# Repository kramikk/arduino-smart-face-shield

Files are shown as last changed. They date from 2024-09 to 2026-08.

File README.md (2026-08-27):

# Arduino Smart Face Shield (2022)

<p align="center">
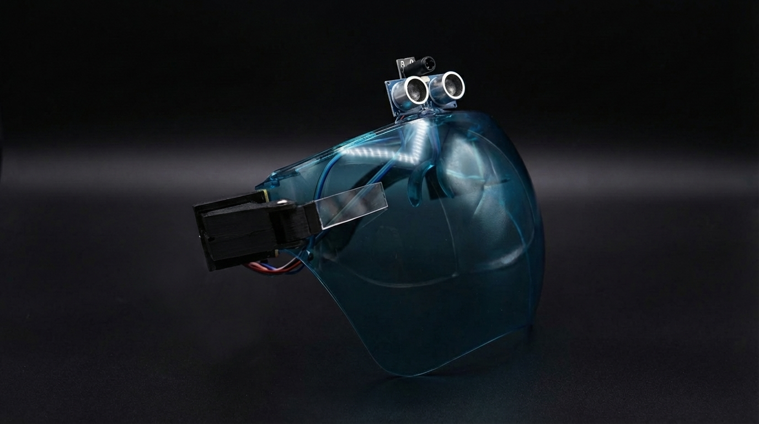
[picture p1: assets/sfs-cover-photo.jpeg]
  
</p>

## Introduction

This project is my Senior High Practical Research 2 Scientific Investigatory Project (SIP), in which it was completed on January 2022. It was developed as a response to the COVID-19 pandemic, aimed at improving public health safety. Our Arduino-based smart face shield was designed to provide a hands-free solution for temperature scanning and monitoring.

The smart face shield detects the temperature of surrounding individuals without any physical contact, offering a fast and effective way to monitor for potential fever—a common symptom of COVID-19. This device not only helps in minimizing close contact but also ensures a quick and efficient method to assess temperatures in public spaces.

This project utilizes an Arduino with an ultrasonic sensor and an infrared temperature sensor to measure both the distance and the temperature of a person. The values are displayed on an OLED screen which the user can view through a reflection, and a vibration motor is triggered if the temperature exceeds a certain threshold (37.5°C). The project also includes a real-time clock (RTC) module to display the current date and time on the OLED display.

## Components

<p align="center">
  Smart Face Shield in action
</p>

- **Arduino Nano** (for portability)
- **Ultrasonic Sensor (HC-SR04)**: Measures distance in centimeters.
- **Infrared Temperature Sensor (MLX90614)**: Measures object and ambient temperature.
- **OLED Display (128x64)**: Displays date, time, temperature, and distance.
- **Vibration Motor**: Activated when the object's temperature exceeds 37.5°C.
- **RTC Module (DS3231)**: Displays the current date and time.
- **Additional Power Supply Pin (VCC2)**: Supplies power to the ultrasonic sensor.

## Libraries Used
You need to install the following libraries in your Arduino IDE:
- [NewPing](https://bitbucket.org/teckel12/arduino-new-ping/wiki/Home): For the ultrasonic sensor.
- [Adafruit MLX90614](https://github.com/adafruit/Adafruit-MLX90614-Library): For the infrared temperature sensor.
- [Adafruit GFX](https://github.com/adafruit/Adafruit-GFX-Library): For controlling the OLED display.
- [Adafruit SSD1306](https://github.com/adafruit/Adafruit_SSD1306): For the OLED screen communication.
- [RTClib](https://github.com/adafruit/RTClib): For the real-time clock module.

## Features
<p align="center">
  Smart Face Shield
</p>

- **Distance Measurement**: Measures the distance using the ultrasonic sensor.
- **Temperature Measurement**: Measures the object's temperature using the MLX90614 sensor.
- **OLED Display**: Displays the current date, time, temperature, and distance.
- **Vibration Alert**: The vibration motor is activated if the object's temperature is equal to or above 37.5°C.
- **Real-Time Clock (RTC)**: Shows the current date and time using the DS3231 module.

## How It Works
<p align="center">
  Smart Face Shield
</p>

1. The ultrasonic sensor detects the distance to an object in centimeters.
2. The infrared temperature sensor measures an object temperature.
3. The current date and time are fetched from the RTC module.
4. If the measured object temperature is greater than or equal to 37.5°C, the vibration motor is triggered.
5. All the data (date, time, distance, temperature) is displayed on the OLED screen which is reflected through a mirror into a transparent surface.
6. The data is also printed to the Serial Monitor for debugging purposes.

## Circuit Diagram
Make sure to connect the following components correctly:

- **Ultrasonic Sensor (HC-SR04)**:
  - Trigger pin to Arduino pin 11
  - Echo pin to Arduino pin 12
  - VCC to Arduino 5V (or additional 5V pin)
  - GND to Arduino GND
- **Infrared Temperature Sensor (MLX90614)**:
  - SDA to Arduino A4
  - SCL to Arduino A5
  - VCC to Arduino 3.3V
  - GND to Arduino GND
- **OLED Display (SSD1306 128x64)**:
  - SDA to Arduino A4
  - SCL to Arduino A5
  - VCC to Arduino 5V
  - GND to Arduino GND
- **RTC (DS3231)**:
  - SDA to Arduino A4
  - SCL to Arduino A5
  - VCC to Arduino 5V
  - GND to Arduino GND
- **Vibration Motor**:
  - Vibration motor pin to Arduino pin 10
  - Ground pin to GND

## Code
You can find the source code in the `asf.ino` file. The main logic involves the following:
- Initialization of all sensors and the OLED screen.
- Continuously fetch and display the date, time, temperature, and distance.
- Activate the vibration motor based on the temperature threshold.

## How to Use
1. **Upload the code** to your Arduino board using the Arduino IDE.
2. **Install the required libraries** in your Arduino IDE if you haven't already.
3. **Connect the components** according to the circuit diagram.
4. Open the **Serial Monitor** to view the real-time data output.
5. Observe the **OLED display** for real-time distance, temperature, date, and time.
6. If the temperature exceeds 37.5°C, the vibration motor will be activated.
7. Once working, print all the parts from [assets folder](https://github.com/kramikkk/arduino-smart-face-shield/tree/main/case-3d-model) and place the components inside it.

## Poster
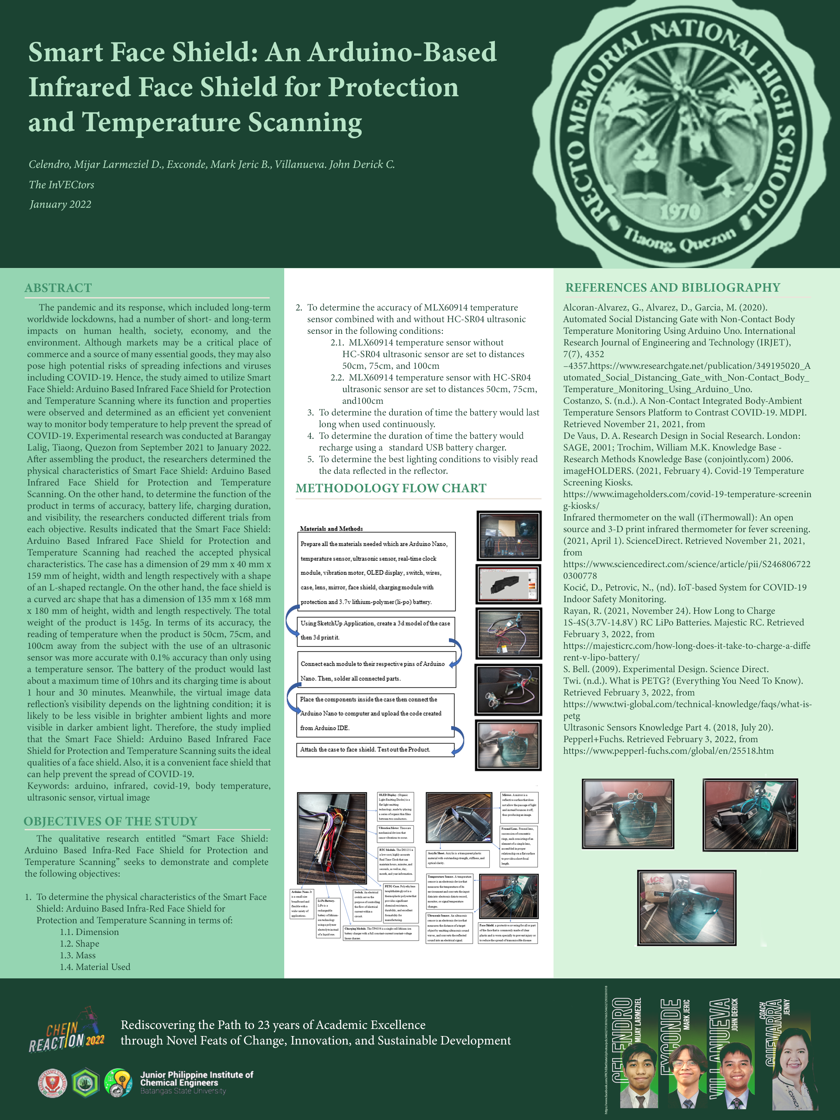
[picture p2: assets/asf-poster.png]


## Extra
[Smart-Face-Shield-Research-Paper.pdf](https://github.com/kramikkk/arduino-smart-face-shield/tree/main/assets/Smart-Face-Shield-Research-Paper.pdf) 
## License
This project is licensed under the MIT License. You are free to use, modify, and distribute this project as long as proper credit is given to the author.

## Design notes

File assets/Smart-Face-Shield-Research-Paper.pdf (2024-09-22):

Smart Face Shield: Arduino Based Infra-Red Face Shield for Protection and Temperature

Scanning

A Research Paper

Presented to the Senior High School Department

Of Recto Memorial National High School

In Partial Fulfilment

Of the Requirements for the Subject

Practical Research

By:

Celendro, Mijay Larmeziel D.

Exconde, Mark Jeric B.

Villanueva, John Derick D.

January 2022

ii

TABLE OF CONTENTS

PRELIMINARIES | PAGES

CHAPTER 1- THE PROBLEM AND ITS BACKGROUND

CHAPTER II- REVIEW OF RELATED LITERATURE

CHAPTER III- RESEARCH METHODOLOGY

iii

CHAPTER IV- PRESENTATION, ANALYSIS, AND INTERPRETATION OF DATA

I. The Physical Characteristics of the Smart Face Shield: Arduino Based Infra-red

Face shield for Protection and Temperature

II. | The accuracy of MLX60914 temperature sensor combined with and without HC-
III. | The duration of time the battery of Smart Face Shield: Arduino Based Infra-red
| Face shield for Protection and Temperature
IV. | The duration of time the battery of Smart Face Shield: Arduino Based Infra-red
| Face shield for Protection and Temperature Scanning would
V. The best lighting conditions to visibly read the data reflected the reflector of the

Smart Face Shield: Arduino Based Infra-red Face shield for Protection and

CHAPTER V- SUMMARY, CONCLUSIONS, AND RECOMMENDATIONS

iv

APPENDICES

v

ABSTRACT

The pandemic and its response, which included long-term worldwide lockdowns, had a

number of short- and long-term impacts on human health, society, economy, and the environment.

Although markets may be a critical place of commerce and a source of many essential goods, they

may also pose high potential risks of spreading infections and viruses including COVID-19.

Hence, the study aimed to utilize Smart Face Shield: Arduino Based Infrared Face Shield for

Protection and Temperature Scanning where its function and properties were observed and

determined as an efficient yet convenient way to monitor body temperature to help prevent the

spread of COVID-19. Experimental research was conducted at Barangay Lalig, Tiaong, Quezon

from September 2021 to January 2022. After assembling the product, the researchers determined

the physical characteristics of Smart Face Shield: Arduino Based Infrared Face Shield for

Protection and Temperature Scanning. On the other hand, to determine the function of the product

in terms of accuracy, battery life, charging duration, and visibility, the researchers conducted

different trials from each objective. Results indicated that | the | Smart Face Shield: Arduino Based
Infrared Face Shield for Protection and Temperature Scanning | had reached the accepted physical

characteristics. The case has a dimension of 29 mm x 40 mm x 159 mm of height, width and length

respectively with a shape of an L-shaped rectangle. On the other hand, the face shield is a curved

arc shape that has a dimension of 135 mm x 168 mm x 180 mm of height, width and length

respectively. The total weight of the product is 145g. In terms of its accuracy, the reading of

temperature when the product is 50cm, 75cm, and 100cm away from the subject with the use of

an ultrasonic sensor was more accurate with 0.1% accuracy than only using a temperature sensor.

The battery of the product would last about a maximum time of 10hrs and its charging time is

about 1 hour and 30 minutes. Meanwhile, the virtual image data reflection’s visibility depends on

the lighting condition; it is likely to be less visible in brighter ambient lights and more visible in

darker ambient light. | Therefore, the study implied that the | Smart Face Shield: Arduino Based

Infrared Face Shield for Protection and Temperature Scanning suits the ideal qualities of a face

shield. Also, it is a convenient face shield that can help prevent the spread of COVID-19.

Keywords: arduino, infrared, covid-19, body temperature, ultrasonic sensor, virtual image

Chapter I

THE PROBLEM AND ITS BACKGROUND

Technology has still risen up for the past years despite the pandemic. In the malls and

airports, they use a device called ‘Kiosks’ to thermal scan the body temperatures of who passes

by. As stated by imageHOLDERS (2021), fever detection is one of the methods in identifying

COVID-19 and other infectious illnesses which may help to reduce the spread. Inspired by the

concept of modern Smart Glasses, Mauer (2016) created an Arduino Glasses: a head-mounted

display (HMD) for Multimeter. This device displays data of a multimeter in form of the virtual

image reflected into the eye. The researchers then used the ideology and design of Mauer’s project

to create Smart Face Shield: Arduino Based Infra-red Face shield for Protection and Temperature

Scanning. Also, the researchers, therefore, conclude that the use of Arduino and Infrared

technology inspired by the concept of thermal and virtual imaging, are the necessary means to

achieve the goals of the research.

Statement of the problem

The qualitative research entitled “Smart Face Shield: Arduino Based Infra-Red Face

Shield for Protection and Temperature Scanning” seeks to demonstrate and complete the

following objectives:

1. To determine the physical characteristics of the Smart Face Shield: Arduino Based Infra-

Red Face Shield for Protection and Temperature Scanning in terms of:

1.1. Dimension

1.2. Shape
1.3. Mass
1.4. Material Used
2. To determine the accuracy of MLX60914 temperature sensor combined with and without

HC-SR04 ultrasonic sensor in the following conditions:

2.1. MLX60914 temperature sensor without HC-SR04 ultrasonic sensor are set to distances

50cm, 75cm, and 100cm

2.2. MLX60914 temperature sensor with HC-SR04 ultrasonic sensor are set to distances

50cm, 75cm, and 100cm

3. To determine the duration of time the battery would last long when used continuously.
4. To determine the duration of time the battery would recharge using a standard USB battery

charger.

5. To determine the best lighting conditions to visibly read the data reflected in the reflector.

Significance of the Study

This study entitled | “Smart Face Shield: Arduino Based Infra-Red Face Shield for
Protection and Temperature Scanning” | aimed to come up with a new way to help prevent the

spread of COVID-19. This will be convenient and useful for awareness and protection.

Moreover, this will ensure people’s health safety against COVID-19. The use of Arduino

and infra-red temperature sensor can greatly help in the pandemic since knowing the body temperature of a person would give great advantages while also using the face shield in protection

for droplets size viruses from people nearby.

This study will be beneficial for people, especially the consumers, workers, and vendors,

as well as producers to be able to reduce the potential further exposure of their health risks while

browsing or selling products at public markets.

This study also benefits future researchers, in adding to the much-needed related literature

review, strengthening conceptual and theoretical framework as well as pursuing this field of the

proposed study and may come up with future innovations using the same materials to contribute

to the development of technology.

In addition, this research can be a good starting point for another or other developmental

researchers to invent a similar product that can be used to help prevent the further spread of the

virus.

The study wanted to prove that with the use of the said product, people can maximize their

protection, especially from the data accuracy of temperature sensors. It can be recharged up fast

and last long for daily convenient and efficient use.

The findings of this study will rebound to the benefit of society considering that thermal

scanning will be a great help on our daily shopping.

The Smart Face Shield: Arduino Based Infra-Red Face Shield for Protection and

Temperature Scanning can be practically useful enough since the need for protection is

increasingly becoming important.

Scope and Delimitation of the Study

The focus of this research paper entitled “Smart Face Shield: Arduino Based Infra-Red

Face Shield for Protection and Temperature Scanning” is to determine the effectiveness and

functionality of using Arduino and infrared technology to read nearby bodies temperature.

The findings of the study were based on the observations that were answered by the five

objectives of the study: (1) physical characteristics of the Smart Face Shield Arduino Based Infra-

Red Face Shield for Protection and Temperature Scanning, (2) accuracy of MLX60914

temperature sensor combined with and without HC-SR04 ultrasonic sensor, (3) duration of time

the battery would last long when used continuously, (4) the duration of time the battery would

recharge using a standard USB battery charger, (5) best lighting conditions to visibly read the data

reflected to the reflector.

In addition, because of the COVID-19, the study and testing of the product will be

conducted within the researchers’ house premises only since they are limited to go outside

considering the quarantine protocols implemented in the community. The respondent person for

testing of the product needs parents’ consent to secure the safety of the person/s who test the

product. However, during the process of this paper, communication through the use of digital

devices and the internet will be considered for research purposes.

The study only used the available market modules and sensor since the researchers aren’t

capable of producing self-made sensors or company devices that can make the product better but

more expensive.

This study was conducted from September 2021 to January 2022.

Conceptual Framework

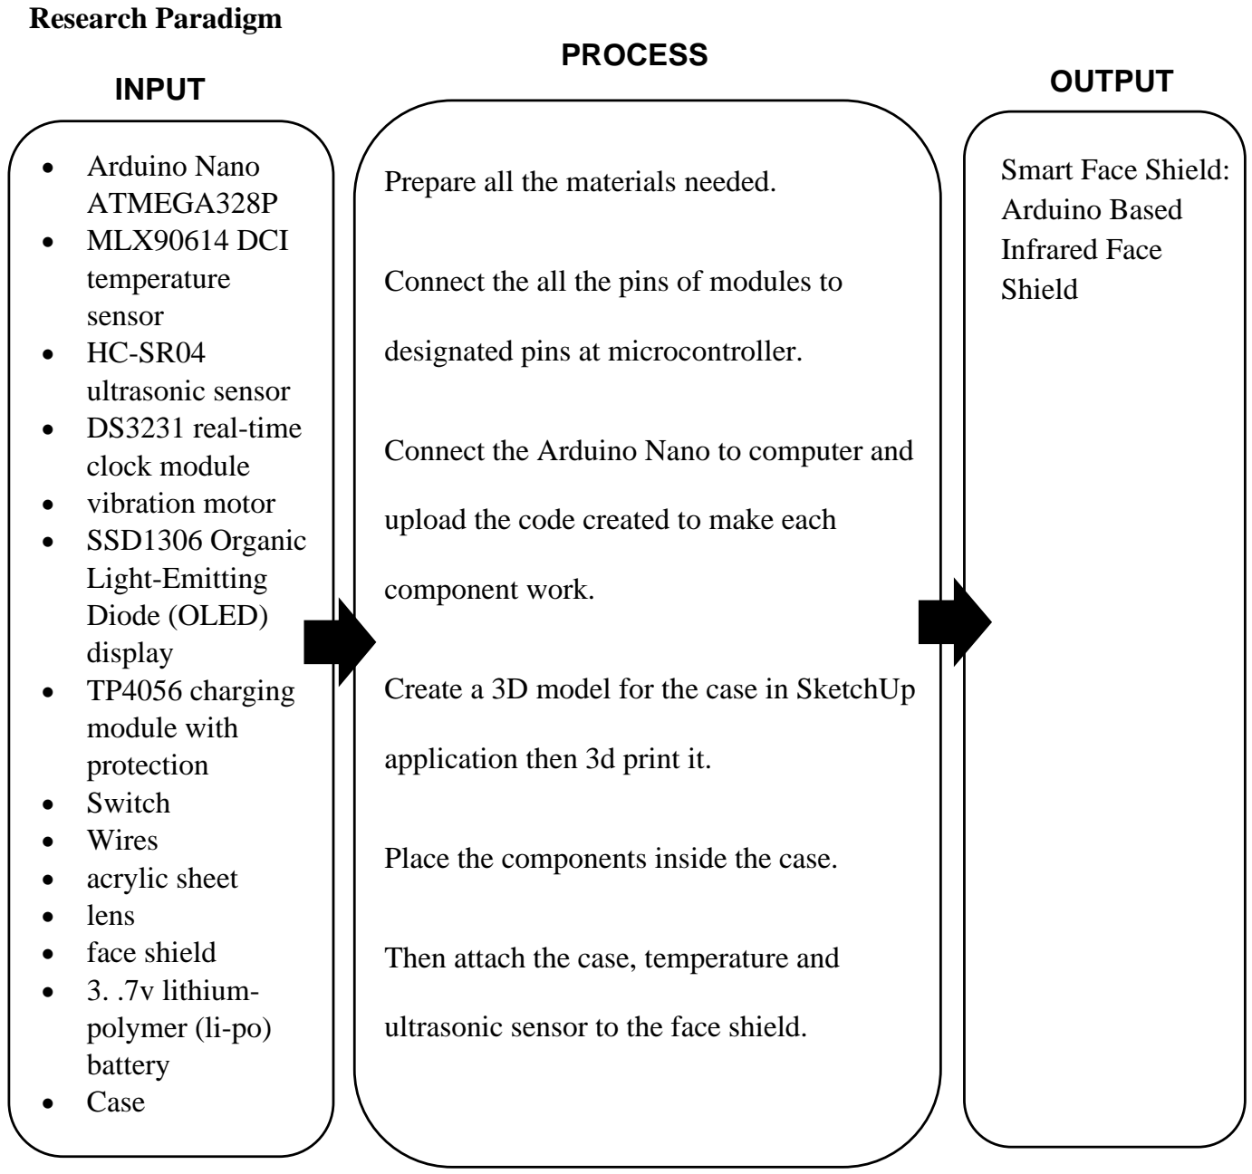
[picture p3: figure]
Research Paradigm; • Arduino Nano ATMEGA328P • MLX90614 DCI temperature sensor • HC-SR04 ultrasonic sensor • DS3231 real-time clock module • vibration motor • SSD1306 Organic Light-Emitting Diode (OLED) display • TP4056 charging module with protection • Switch • Wires • acrylic sheet • lens • face shield • 3. .7v lithium- polymer (li-po) battery • Case; Smart Face Shield: Arduino Based Infrared Face Shield; Prepare all the materials needed.; Connect the all the pins of modules to; designated pins at microcontroller.; upload the code created to make each; component work.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

Figure 1. Input, Process, Output (IPO) of the Smart Face Shield: Arduino Based Infrared Face shield for temperature scanning and protection

Figure 1 shows the Input, Process, and Output wherein the inputs are the Arduino Nano

ATMEGA328P, MLX90614 DCI temperature sensor, HC-SR04 ultrasonic sensor, DS3231 real-

time clock module, vibration motor, SSD1306 Organic Light-Emitting Diode (OLED) display,

Connect the Arduino Nano to computer and

Create a 3D model for the case in SketchUp switch, wires, acrylic sheet, lens, mirror, face shield, TP4056 charging module with protection,

3.7v lithium-polymer (Li-po) battery and case. The process shows that OLED display, RTC

module, temperature sensor, ultrasonic sensor, vibration motor, charging module are to be

connected to the Arduino Nano. The battery would be connected to the charging module. 3d model

of the case should be created and printed. The components would be placed inside the case. Lastly,

Temperature and the ultrasonic sensor would be placed on the forehead level of the face shield

while the case is attached to the right side.

Definition of terms

For clear understanding, the following terms were defined conceptually or operationally:

Arduino - Open-source electronic prototyping platform enabling users to create interactive

electronic objects.

Infra-red - Is electromagnetic radiation (EMR) with wavelengths longer than those of visible

light.

Infra-red sensor - An infrared sensor (IR sensor) is a radiation-sensitive optoelectronic

component with spectral sensitivity in the infrared wavelength range 780 nm … 50 µm.

Covid-19 - stands for Coronavirus Disease 2019 and is a highly contagious disease caused by a

newly discovered coronavirus.

Temperature - is a measure of the average kinetic energy of the atoms or molecules in the system.

Quarantine Protocols - separating and restricting the movement of the people who are exposed

or are potentially exposed to a contagious disease

Pandemic - refers to the proficiency of disease (especially, a virus) to spread or be prevalent to a

country or the whole world, affecting almost the whole population.

Sensor - a device that detects or measures a physical property and records, indicates, or otherwise

responds to it.

Thermal Imaging - Thermal imaging is simply the process of converting infrared (IR) radiation

(heat) into visible images that depict the spatial distribution of temperature differences in a scene

viewed by a thermal camera.

Chapter II

REVIEW OF RELATED LITERATURE AND STUDIES

This chapter presents the different local and foreign literature and studies that are relevant

to the present research.

Related Studies

Local Studies

In a study conducted by Alcoran-Alvarez, et al. (2020) entitled “Automated Social

Distancing Gate with Non-Contact Body Temperature Monitoring using Arduino Uno”, there is a

Thermal gate with the components of Arduino R3, a Long-range Infrared proximity sensor,

Ultrasonic sensor, Speaker, Infrared proximity sensor, Infrared thermometer sensor, LCD module,

Buzzer.

In their research product, there is a long-range sensor (infrared proximity) that points to

the ground to detect the incoming person into the gate, then the speaker sends a signal to the other

person, the person that enters the limit of 1-meter social distancing after the point of entry behind

the first person and within the middle of the gate the body temperature will be scanned and

displayed on the LCD and the buzzer will, alarm if the person enters the gate has a body

temperature greater than 37.5 degrees Celsius to notify the assigned gate personnel.

They have been proven that social distancing can be followed and at the same time/body

temperature scanning of one person can also be done.

Foreign Studies

In the study entitled “Infrared thermometer on the wall (iThermowall): An open-source

and 3-D print infrared thermometer for fever screening” by Abuzairi, Sumantri, et, al. (2020), they

a made low-cost non-contact infrared thermometer in the wall that they called iThermowall. This

device is designed to automatically measure and detect the body’s temperature where there is no

one to operate manual thermometers. The goal of their product is to address the obstacle in using

a non-contact handheld IR thermometer, which is proven to be effective yet still depends on the

operator and the distance between foreheads.

To make the product easily reproducible, the researchers used a readily accessible module

and a 3-D printer. The electronic components consist of a microcontroller unit (MCU), OLED

display, LED, infrared thermometer sensor, infrared proximity sensor, buzzer, charger module,

step-up converter, and battery. The MCU employed open-source Arduino Nano microcontrollers

to read the data from the Infrared Thermometer then write the data into an OLED display.

Moreover, according to Costanzo and Flores (2020) in their study entitled ‘A Non-Contact

Integrated Body-Ambient Temperature Sensors Platform to Contrast COVID-19” the combination

of an infrared thermometer with a capacitive humidity sensor can provide a quick and accurate

tool for remotely monitoring both ambient and body temperature in pandemic circumstances such

as COVID-19. They used an infrared sensor for measuring body temperature and a capacitive

relative humidity (RH) sensor for the ambient temperature, while the Arduino microcontroller

displayed the data collected.

Another research entitled “IoT based System for COVID 19 Indoor Safety Monitoring” by

Petrović and Kocić (2020), made an IoT device intended for contactless temperature sensing, mask detection, and social distancing check. Arduino Uno relies upon as a subsystem for contactless

temperature sensing with the use of infrared sensors or thermal cameras.

On the other hand, leveraging computer vision techniques on camera-equipped Raspberry

Pi is used for mask detection and for checking social distancing.

As stated in the study Nethra, Nagdeepa, et, al. (2021) entitled “Contactless Mobile

Thermometer”, social distancing can’t be ensured by conventional thermometers thus the

researchers decided to produce Bluetooth-primarily based contactless mobile thermometer with

thermal screening functionality delivered to cellular phones. To show the temperature Arduino

Nano is necessary as well as an infrared sensor. The objective of their study is to read temperature

easily and handily that have broad variation for dimension temperature where you can display

accurate temperature scanning in a virtual manner.

CHAPTER III

RESEARCH METHODOLOGY

This chapter presents and discusses the methodology and procedures applied in the

conduct of the study. It contains the materials and methods, research design, research procedures,

and statistical treatment.

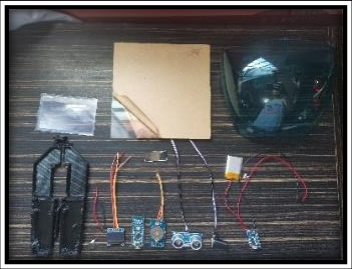
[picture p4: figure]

Materials and Methods

Prepare all the materials needed which are Arduino Nano,

temperature sensor, ultrasonic sensor, real-time clock

module, vibration motor, OLED display, switch, wires,

case, lens, mirror, face shield, charging module with

protection and 3.7v lithium-polymer (li-po) battery.

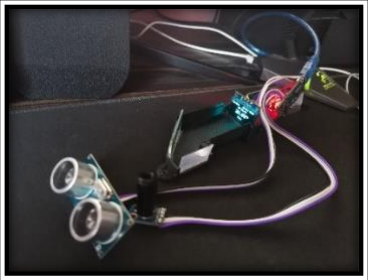
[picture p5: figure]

Connect each module to their respective pins of Arduino

Nano. Then, solder all connected parts.

Place the components inside the case then connect the

Arduino Nano to computer and upload the code created

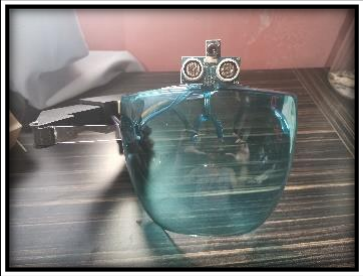
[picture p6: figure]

from Arduino IDE.

Attach the case to face shield. Test out the Product.

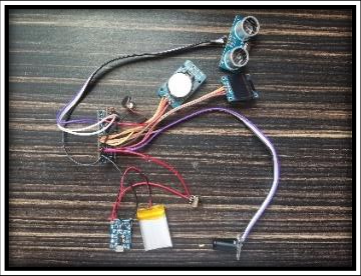
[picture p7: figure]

Using SketchUp Application, create a 3d model of the case

then 3d print it.

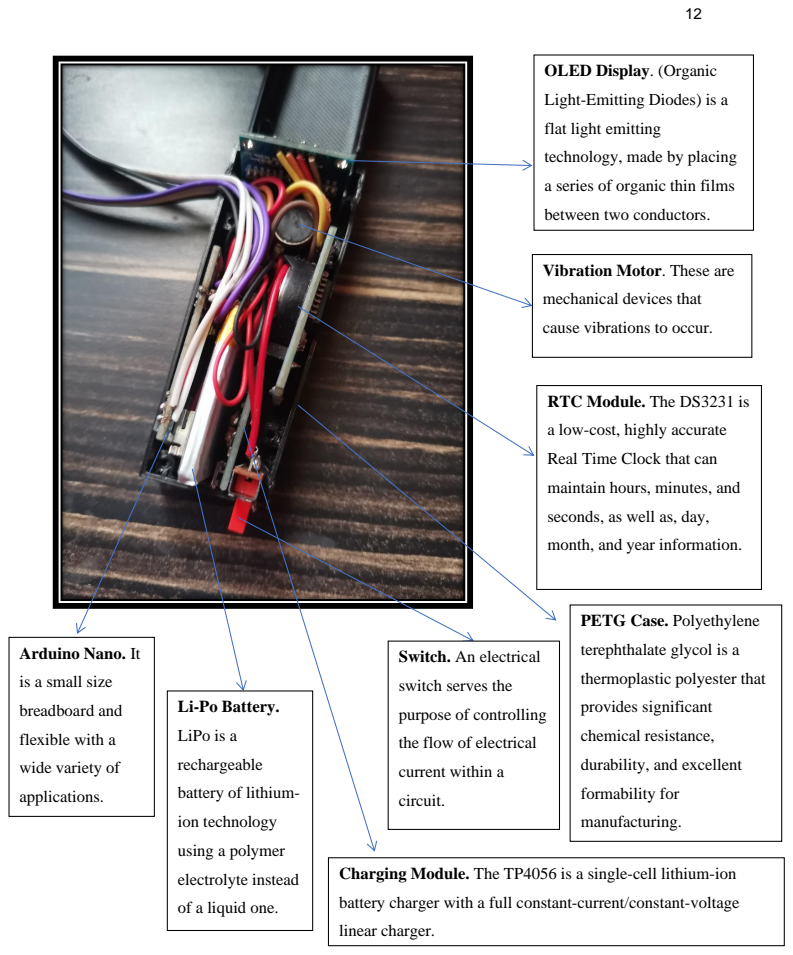
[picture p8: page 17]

OLED Display. (Organic
Light-Emitting Diodes) is a
flat light emitting
technology, made by placing
a series of organic thin films
between two conductors.

Vibration Motor. These are
mechanical devices that
cause vibrations to occur.

RTC Module. The DS3231 is
a low-cost, highly accurate
Real Time Clock that can
maintain hours, minutes, and
seconds, as well as, day,
month, and year information.

PETG Case. Polyethylene
terephthalate glycol is a
thermoplastic polyester that
provides significant
chemical resistance,
durability, and excellent
formability for
manufacturing.

Arduino Nano. It
is a small size
breadboard and
flexible with a
wide variety of
applications.

Switch. An electrical
switch serves the
purpose of controlling
the flow of electrical
current within a
circuit.

Li-Po Battery.
LiPo is a
rechargeable
battery of lithium-
ion technology
using a polymer
electrolyte instead
of a liquid one.

Charging Module. The TP4056 is a single-cell lithium-ion
battery charger with a full constant-current/constant-voltage
linear charger.

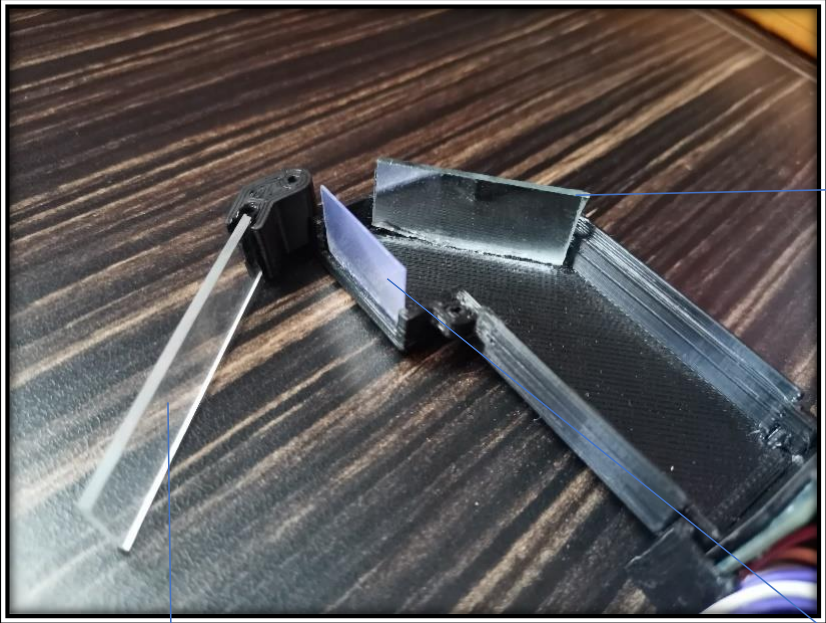
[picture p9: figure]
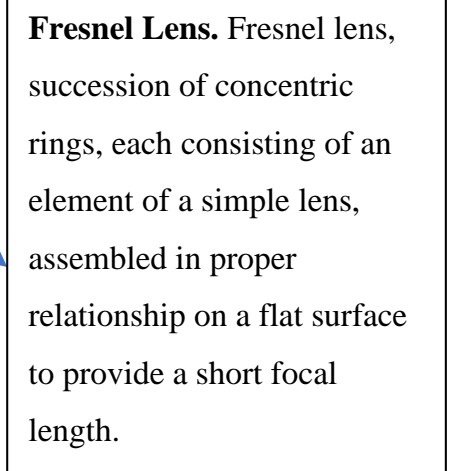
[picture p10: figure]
Fresnel Lens. Fresnel lens,; succession of concentric; rings, each consisting of an; element of a simple lens,; assembled in proper; relationship on a flat surface; to provide a short focal; length.
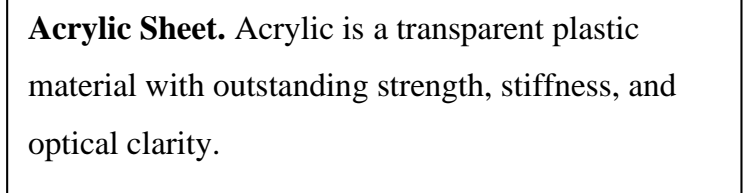
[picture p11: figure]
optical clarity.

Acrylic Sheet. Acrylic is a transparent plastic

material with outstanding strength, stiffness, and

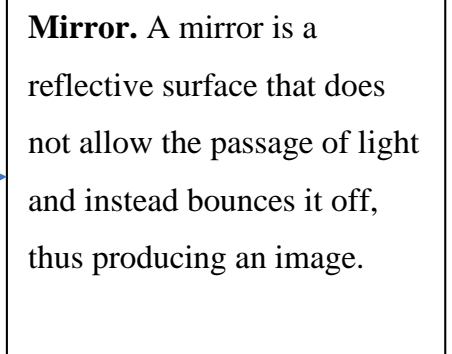
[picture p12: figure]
Mirror. A mirror is a; reflective surface that does; not allow the passage of light; and instead bounces it off,; thus producing an image.
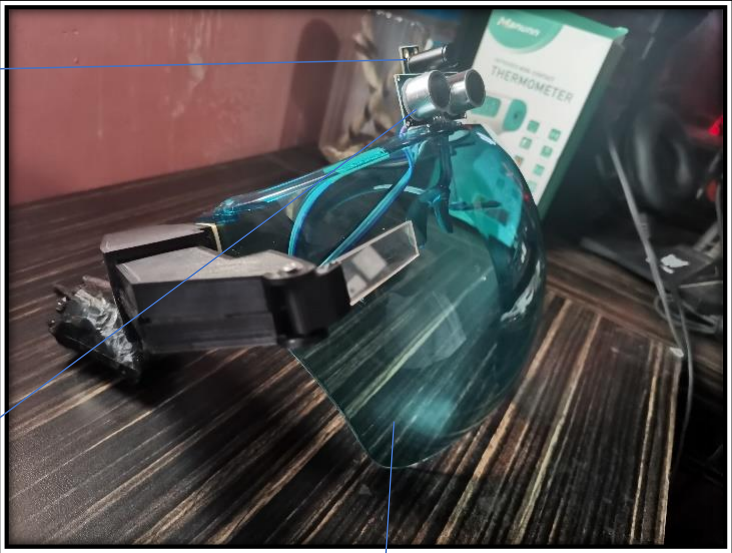
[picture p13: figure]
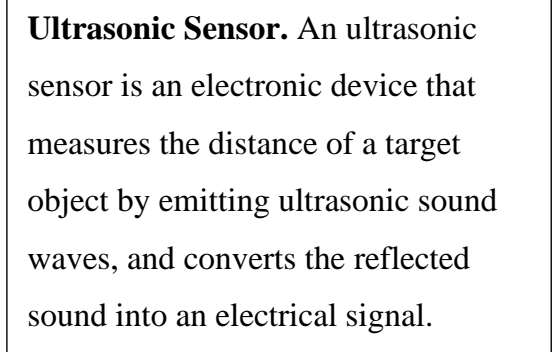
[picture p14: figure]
Ultrasonic Sensor. An ultrasonic; sensor is an electronic device that; measures the distance of a target; object by emitting ultrasonic sound; waves, and converts the reflected; sound into an electrical signal.
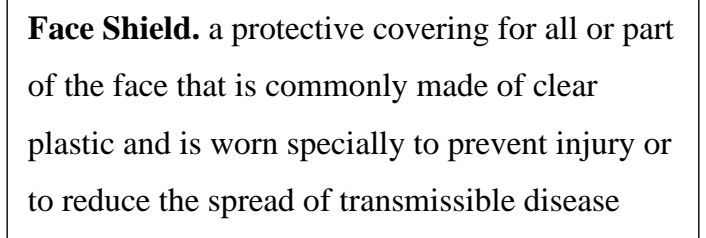
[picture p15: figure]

Face Shield. a protective covering for all or part

of the face that is commonly made of clear

plastic and is worn specially to prevent injury or

to reduce the spread of transmissible disease

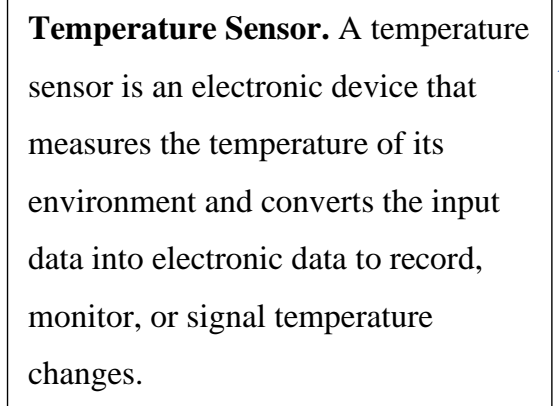
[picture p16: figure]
Temperature Sensor. A temperature; sensor is an electronic device that; measures the temperature of its; environment and converts the input; data into electronic data to record,; monitor, or signal temperature; changes.

Research Design

The study employed an experimental research design to determine the functionality and

capability of Smart Face Shield: Arduino Based Infra-Red Face Shield for Protection and

Temperature Scanning in detecting fever which is one of the most common symptoms of COVID-

19 and its variants.

According to S. Bell (2009), experimental design is the process of carrying out research in

an objective and controlled fashion so that precision is maximized and specific conclusions can be

drawn regarding a hypothesis statement.

As stated by De Vaus (2006), the research design refers to the overall strategy that you

choose to integrate the different components of the study coherently and logically, thereby,

ensuring you will effectively address the research problem; it constitutes the blueprint for the

collection, measurement, and analysis of data.

This study is experimental research for the product that needed several trials and tests to

identify the functionality of the proposed Smart Face Shield: Arduino Based Infra-red Face shield

for Protection and Temperature Scanning that will be beneficial in maintaining safety measures

while going to crowded places despite COVID-19 pandemic.

Statistical Treatment

All qualitative and quantitative data that are needed were gathered.

For the second objective, the Smart Face Shield Arduino Based Infra-Red Face Shield for

Protection and Temperature Scanning was tested to determine the accuracy of both temperature and ultrasonic sensor under different distance settings (50cm, 75cm, and 100cm). Target

temperature (nearest distance), trial 1, trial 2, and trial 3 were determined by collecting the average

of each twenty-five (25) data in a span of 30 seconds using the formula average =

Total Sum of Data
Number of Data

. The average of trial 1, 2 and 3 are also computed using the formula average =

Total Sum of Trials
Number of Trials

to compare the accuracy of sensors from target temperature. Also, the difference

was | calculated | using | the | formula | Absolute Error = |Experimental Value −

Tℎeoretical Value| the accuracy was calculated using the formula of percentage error which is

percentage error = |

Experimental Value−Tℎeoretical Value
Tℎeoretical Value | | × 100. These formulas are from a
web blog of | Scott Laughlin (n.d). | Furthermore, tape measure is used to navigate the right

measurement of distance settings and to compare the distance given by the ultrasonic sensor.

For the third and fourth objective, the duration of time the battery would last long when

used continuously and the duration of time the battery would recharge using a standard USB

battery charger was determined by using a timer. Third objective consists of three settings (Max-

Nom, Max-Min, Max-Cut) and each has three trials (1,2,3). Fourth objective also consists of three

settings (Cut-Min, Cut- Nom, Cut-Max) and each also has three trials (1,2,3). The averages of each

trials in each objective were also calculated using the formula of average =

Total Sum of Trials
Number of Trials

CHAPTER IV

PRESENTATION, ANALYSIS, AND INTERPRETATION OF DATA

This chapter presents all the gathered data by the researchers that deal with the presentation,

analysis, and interpretation of results through the researchers’ observation of the Smart Face

Shield: Arduino Based Infra-Red Face Shield for Protection and Temperature Scanning. The data

are presented in tabular form and followed by interpretation.

I. The Physical Characteristics of the Smart Face Shield: Arduino Based Infra-

Red Face Shield for Protection and Temperature Scanning

Dimension | | Case | Face Shield
| Height | 29 mm | 135 mm
| Width | 40 mm | 168 mm
| Length | 159mm | 180 mm
Shape | | L-shaped rectangle | Arc Curved
Mass | | 80 g | 65 g
Material Used | Case | Polyethylene terephthalate glycol (PETG)
| Lens | Fresnel lens 110mm focal length, 3x magnification
| Reflector | Transparent acrylic sheet 1.5mm
| Battery | Lithium-Ion Polymer 3.7v 400mAh
| Modules | OLED display, RTC module, Arduino Nano, TP4056 module, Ultrasonic Sensor, Temperature sensor

Table 1 The Physical Properties of the Smart Face Shield: Arduino Based Infra-Red

Face Shield for Protection and Temperature Scanning

Table 1 shows the physical properties of the Smart Face Shield: Arduino Based

Infra-red Face shield for Protection and Temperature Scanning in terms of dimension,

shape, mass, and materials. The dimension, shape, and mass of the Smart Face Shield:

Arduino Based Infra-red Face shield for Protection and Temperature Scanning is divided

into two parts: Case & Face Shield. The case’s dimension measures 29 mm x 40 mm x 159

mm of height, width, and length respectively. On the other hand, the face shield’s

dimension measures 135 mm x 168 mm x 180 mm of height, width, and length

respectively. In terms of its shape & mass, the case of the product is an L-shaped rectangle

with a mass of 80g, and the Face shield is curved arc-shaped with a mass of 60g.

Also, the case of the product is made of Polyethylene terephthalate glycol (PETG),

the lens is made of a Fresnel lens with 110mm focal length & 3x magnification. The

reflector of the product is made of a 1.5mm thick transparent acrylic sheet, the battery used

in the product is a 3.7v & 400mAh lithium-ion polymer while the modules used are OLED

display, RTC module, Arduino Nano, TP4056 module, Ultrasonic Sensor, Temperature

sensor.

In addition, based on the mass of the product weighs 165g and we observed that the

product is not too heavy and may not cause a hassle to equip.

According to www.twi-global.com, the Polyethylene terephthalate glycol (PETG)

is a thermoplastic polyester that delivers significant chemical resistance, durability, and

formability in manufacturing. Also, the Polyethylene terephthalate glycol (PETG) has

greater strength and durability, as well as being more impact resistant and better suited to

the higher temperatures.

Moreover, the lens used in the product is a Fresnel lens, according to Magnifiers

(n.d.) Fresnel lens is a magnifying glass lens that design enables the construction of lenses

of large aperture and short focal length without the weight and volume of material which

would be required in conventional lens design and also compare to the other lens Fresnel

lens is much thinner, lighter, larger aperture, passing more ray and lower cost.

With the use of a transparent acrylic sheet, the data from the OLED was shown as a

virtual image. According to www.curbellplastics.com acrylic is a transparent plastic

material with strength, stiffness, and optical clarity also, it has superior weathering

properties unlike other transparent plastic. Acrylic sheet is like a glass in qualities like

clarity and transparency but unlike glass it is not too heavy and have much more impact

resistant than glass.

II. | The accuracy of MLX60914 temperature sensor combined with and without
| HC-SR04 ultrasonic sensor
Distance | Target Body Temperature | Trial 1 | Trial 2 | Trial 3 | Average Temperature | Difference | Accuracy
50cm | 35.96 °C | 35.44 °C | 35.58 °C | 35.54 °C | 35.52 °C | ±0.44˚C | 1.2%
75cm | 36.18 °C | 35.37 °C | 35.43 °C | 35.39 °C | 35.40 °C | ±0.78˚C | 2.2%
100cm | 36.35 °C | 35.17 °C | 35.16 °C | 35.24 °C | 35.19 °C | ±1.16˚C | 3.2%

Table 2.1 The accuracy of MLX60914 temperature sensor without HC-SR04

ultrasonic sensor

The first row shows the variables needed to determine the objective. In the second

row, shows the accuracy of temperature that the Smart Face Shield: Arduino Based Infra-

red Face shield for Protection and Temperature Scanning can detect if it is 50 centimeters away from the subject with an initial temperature of 35.96 °C. There are three trials

conducted to determine the average temperature of a person with just using a temperature

sensor and without an ultrasonic sensor. The first trial detected a temperature of 35.44 °C,

the second trial was 35.58 °C, and the third trial was 35.54 °C. With these three trials the

average temperature was 35.52 °C. This only means that the average temperature is quite

accurate with the target body temperature with a difference of ±0.44°C and accuracy of

1.2%, considering the 50 centimeters distance.

In the third row, shows the accuracy of temperature that the Smart Face Shield:

Arduino Based Infra-red Face shield for Protection and Temperature Scanning can detect

if it is 75 centimeters away from the subject with an initial temperature of 36.18 °C. Also,

three trials were conducted to determine the average temperature of a person with only a

temperature sensor and without an ultrasonic sensor. In the first trial the temperature

detected was 35.37 °C, while 35.43 °C and 35.39 °C as for the second and third trial.

Making an average temperature of 35.40 °C. As the distance between the product and

subject increased, the average temperature became inaccurate with the initial temperature,

giving a difference of ±0.78°C and accuracy of 2.2%. It is because Infrared thermometer

will only give an accurate reading if it is close enough with the subject.

Lastly, in the fourth row shows the accuracy of temperature that the Smart Face

Shield: Arduino Based Infra-red Face shield for Protection and Temperature Scanning can

detect if it is 100 centimeters away from the subject with an initial temperature of 36.35

°C. To determine the average temperature of a person using only a temperature sensor and

without an ultrasonic sensor, there were three trials conducted. The three trials detected the

temperature of 35.17 °C, 35.16 °C and 35.24 °C respectively. The average temperature for these trials was 35.19 °C. Increasing the distance with another 25 centimeters, making the

product 100 centimeters away from the subject; the reading of temperature became more

inaccurate with a difference of ±1.16°C and accuracy of 3.2%. It is clear that using a

temperature sensor alone and not combining it with an ultrasonic sensor, the accuracy of

person’s temperature scanning is decreasing as the distance of from the product is

increasing.

According to Fluke (2021), every infrared thermometer has a "distance-to-spot"

(D:S) ratio that tells you the diameter of the area being measured compared to the distance

from the target. For some instances, if your thermometer has a distance-to-spot ratio of

12:1, it measures an approximately one-inch-diameter spot when it's 12 inches from the

target (about 2.5 cm at 30 cm). If you try to use that thermometer to measure a two-inch

(5-cm) area from even just a few feet (1 m) away, you're not going to get an accurate result

because the thermometer will also be measuring the temperature outside the area you want

to measure.

Distance | Target Body Temperature | Trial 1 | Trial 2 | Trial 3 | Average Temperature | Difference | Accuracy
50cm | 35.51˚C | 35.53˚C | 35.54˚C | 35.51˚C | 35.53˚C | ±0.02˚C | 0.1%
75cm | 35.62˚C | 35.59˚C | 35.56˚C | 35.58˚C | 35.58˚C | ±0.04˚C | 0.1%
100cm | 35.59˚C | 35.54˚C | 35.58˚C | 35.59˚C | 35.57˚C | ±0.02˚C | 0.1%

Table 2.2 The accuracy of MLX60914 temperature sensor combined with HC-SR04

ultrasonic sensor

The first row shows the variables needed to determine the objective. In the second

row, shows the accuracy of temperature that the Smart Face Shield: Arduino Based Infrared Face shield for Protection and Temperature Scanning can detect if it is 50 centimeters

away from the subject with an initial temperature of 35.51˚C. Three trials were conducted

to determine the average temperature of a person using temperature sensor combined with

an ultrasonic sensor. In the first trial the temperature detected was 35.53˚C, while 35.54˚C

and 35.51˚C as for the second and third trial. The average temperature for these trials was

35.53˚C. This means that there are now only ±0.02 ˚C difference in average and initial

temperature and accuracy of 0.1% with the use of ultrasonic sensor, unlike when the

researchers only used a thermometer, it gave a difference of ±0.44°C and accuracy of 1.2%

with just a distance of 50 cm.

In third row, shows the accuracy of temperature that the Smart Face Shield:

Arduino Based Infra-red Face shield for Protection and Temperature Scanning can detect

if it is 75 centimeters away from the subject with an initial temperature of 35.62˚C. To

determine the average temperature of a person using temperature sensor combined with an

ultrasonic sensor, there were three trials conducted. The first trial detected a temperature

of 35.59˚C, the second trial was 35.56˚C, and the third trial was 35.58˚C. Making an

average temperature of 35.58˚C. In the previous trials, when the distance between the

product and subject was increased into 75 centimeters, the accuracy in readings dropped

rapidly. But using an ultrasonic sensor, the reading in the temperature is still accurate

despite of the increase in distance having a difference of ±0.04 ˚C in the initial and average

temperature and accuracy of 0.01%.

Lastly, in fourth row shows the accuracy of temperature that the Smart Face Shield:

Arduino Based Infra-red Face shield for Protection and Temperature Scanning can detect

if it is 100 centimeters away from the subject with an initial temperature of 35.59˚C. There are three trials conducted to determine the average temperature of a persson using a

temperature sensor combined with an ultrasonic sensor. The three trials detected the

temperature of 35.54˚C, 35.58˚C, and 35.59˚C respectively. With these three trials the

average temperature was 35.57˚C. Even the distance was expanded up to 100 centimeters,

the reading of temperature is still accurate with just a difference of ±0.02 ˚C and accuracy

of 0.01%. Distinct from the first set of trials when ultrasonic sensor was not used, where

the temperature became more inaccurate once the distance was increased into 100

centimeters. This means that using HC-SR04 ultrasonic sensor along with MLX60914

temperature sensor will give a more accurate temperature even if the distance of the product

from the subject is increasing.

According to www.pepperl-fuchs.com, most of these ultrasonic sensors are

equipped with temperature probes whose measurements are used to correct the measured

distances. This compensation is performed over the entire working range of the ultrasonic

sensors from -25° C to +70° C and allows measurement accuracies of approximately ±1.5%

to be achieved. Also, according to randomnerdtutorials.com, The HC-SR04 ultrasonic

sensor uses sonar to determine the distance to an object. This sensor reads from 2cm to

400cm (0.8inch to 157inch) with an accuracy of 0.3cm (0.1inches), which is good for most

hobbyist projects.

III. | The duration of time the battery of Smart Face Shield: Arduino Based Infra-
| Red Face Shield for Protection and Temperature Scanning would discharge.
Variables | Voltage of Lithium Ion-Polymer Battery | Time Duration
Trial 1 | Trial 2 | Trial 3
Maximum voltage – Nominal voltage | 4.2 – 3.7v | 3 hours 22 minutes | 3 hours and 49 minutes | 3 hours and 11 minutes
Maximum voltage – Minimum safety voltage | 4.2 – 3.2v | 7 hours and 45 minutes | 9 hours and 40 minutes | 7 hours and 26 minutes
Maximum voltage -Cut-off voltage of battery | 4.2 – 2.8v | 8 hours and 10 minutes | 10 hours and 2 minutes | 8 hours and 9 minutes

Table 3 The duration of time the battery of Smart Face Shield: Arduino Based

Infra-red Face shield for Protection and Temperature Scanning would discharge.

The Table 3 displays the duration of time that the Smart Face Shield: Arduino

Based Infra-Red Face Shield for Protection and Temperature Scanning’s battery would

discharge.

Three trials were conducted to know how long the Li-Po Battery would last and

discharge from its maximum voltage of 4.2 v to its nominal voltage of 3.7v. The battery

lasts 3 hours 22 minutes in the first trial, 3 hours and 49 minutes in the second trial, while

3 hours and 11 minutes from its last trial and with an average time duration of 3 hours and

27 minutes.

The battery of the product is discharge after it reached the minimum safety voltage

(3.2v) from its maximum voltage (4.2v). In the first trial it takes 7 hours and 45 minutes

before reaching the minimum safety voltage, 9 hours and 40 minutes in the second trial,

and 7 hours and 26 minutes in trial third trial and with an average time duration of 8 hours

and 4 minutes.

To determine the time before the battery, reach its cut-off voltage, which is 2.8v,

researchers made another three trials. And as seen on the table, on the first trial, it will take

8 hours and 10 minutes before the battery reaches its cut-off voltage, while 10 hours and 2

minutes in the second trial, and 8 hours and 9 minutes in the final trial and with an average

time duration of 9 hours and 14 minutes

This only means that when the device reaches approximately 9 hours of continuous

usage, it will shut down on its own due to programmed cut-off voltage of the battery (2.8v)

and cut-off voltage of the charging module (2.5v). This is just sufficient since according to

The Nature of the Americans (n.d.), out of 5,550 adults, over 60% of adults report spending

5 or less hours outside in nature each week.

IV. | The duration of time the battery of Smart Face Shield: Arduino Based Infra-
| Red Face Shield for Protection and Temperature Scanning would charge.
Variables | Voltage of Lithium Ion-Polymer Battery | Time Duration
Trial 1 | Trial 2 | Trial 3

Cut-off voltage of battery – Minimum safety voltage | 2.8 - 3.2v | 1minute and 22 seconds | 1 minute and 31 seconds | 1 minute and 27 seconds
Cut-off voltage of battery – nominal voltage | 2.8 - 3.7v | 29 minutes and 43 seconds | 30 minutes and 57 seconds | 30 minutes and 28 seconds
Cut-off voltage of battery – maximum voltage | 2.8 - 4.2v | 1hour and 15 minutes | 1 hour and 31 minutes | 1 hour and 28 minutes

Table 4 The duration of time the battery of Smart Face Shield: Arduino Based

Infra-red Face shield for Protection and Temperature Scanning would charge.

Table 4 shows the time duration of Smart Face Shield: Arduino Infra-red Based Face

Shield for Protection and Temperature Scanning would it charge.

Three trials were conducted to know the duration of time needed for lithium ion-

polymer battery to charge from its cut-off voltage (2.8v) to minimum safety voltage (3.2v)

through the charging module using a UBS cable. The battery took 1 minute & 22 seconds

to charge on the first trial, 1 minute & 31 seconds to charge on the second trial, while 1

minute & 27 seconds to charge on the third trial and with an average time duration of 1

minute and 27 seconds

To determine the duration of time the battery would charge from cut-off voltage

(2.8v) to nominal voltage (3.7v), three trials were also conducted. On the first trial, it took

29 minutes and 43 seconds to charge the battery. On the second trial, it took 30 minutes

and 57 seconds to charge the battery. While on the third trial, it took 30 minutes and 28

seconds to charge the battery with an average time duration of 30 minutes and 10 seconds

Lastly, three trials were also conducted to determine the duration of time the

battery would charge from the cut-off voltage (2.8) to maximum voltage (4.2). The

battery took 1 hour and 15 minutes to charge on the first trial, it took 1 hour and 31

minutes to charge on the second trial, while it took 1 hour and 28 minutes to charge on

the third trial and with an average time duration of 1 hour and 25 minutes

This only means that it will take an approximately 1 hour and a half in order to

fully charge the product. According to Rayan (2021), normally, it takes 30-60 minutes to

charge a LiPo battery. However, the charging time is reliant on the size of the battery or

cell count. Your charger’s power output and capacity are also a determinant in this case.

The battery type and the voltage play an important role as well.

V. The best lighting conditions to visibly read the data reflected to the reflector of

the Smart Face Shield: Arduino Based Infra-red Face shield for Protection and

Temperature Scanning.

MATERIAL USED | Visibility
Transparent acrylic sheet | Setting | Low | Mid | High
| Daylight | /
| Nightlight | | | /
| Shady light | | /
| Fluorescent lamp light | | /
| Bulb light | | /

Table 5 The best lighting conditions to visibly read the data reflected to the reflector

of the Arduino Based Infra-Red Face Shield for Protection and Temperature

Scanning

Table 5 shows the best lighting condition to visibly see the data reflected to the

reflector of the Smart Face Shield: Arduino Based Infra-red Face shield for Protection and

Temperature Scanning using an acrylic sheet as a reflector. This table shows five lighting

setting (Daylight, Shady light, Night light, Fluorescent lamp light, and bulb light).

Each setting has three conditions (Low, Mid, High) which are used to determine

the visibility of data reflected. In daylight setting, the virtual image data reflection is at low

visibility while in nightlight setting, the virtual image data reflection is at high visibility.

In the shady light, fluorescent lamp, and bulb light settings, the virtual image data reflection

is at mid visibility.

This only means that the brighter the ambient light is - the lower the visibility of

the virtual image, while the darker the ambient light is - the higher the visibility of the

virtual image.

CHAPTER V

SUMMARY, CONCLUSIONS, AND RECOMMENDATIONS

This chapter presents the summary, which discusses briefly the conclusions that refer to

the ideas drawn from the findings of this study and recommendations, which give suggestions to

the other researchers that might have similar studies about the research topic.

Summary

The study entitled “Smart Face Shield: Arduino Based Infra-Red Face Shield for Protection

and Temperature Scanning” was focused on the development of a technological device to assist

people on the global pandemic and identifying its physical characteristics, functionality and

efficiency.

This study would benefit people whom always go outside for work, groceries, food, and

etc. This will be convenient and helpful for its functionality which helps to protect, to be aware,

and monitor the temperature of the nearby people at public places.

This research sought to answer the following objectives, (1) Determine the physical

characteristics of the Smart Face Shield: Arduino Based Infra-Red Face Shield for Protection and

Temperature Scanning in terms of dimension, shape and mass, (2) Determine the accuracy of

MLX60914 temperature sensor combined with and without HC-SR04 ultrasonic sensor, (3)

Determine the duration of time the battery would last long when used continuously, (4) Determine

the duration of time the battery would recharge using a standard USB battery charger, (5)

Determine the best lighting conditions to visibly read the data reflected to the reflector.

The researchers gathered data through trials and observations. After the data were gathered,

the researchers presented, analyzed, and interpreted them.

With that, the researchers made conclusions and recommendations of the study.

Summary of Findings

After gathering all the needed data, the findings were revealed as follows:

1. The dimension, shape and mass of the Smart Face Shield: Arduino Based Infra-Red Face

Shield for Protection and Temperature Scanning is divided into two parts: Case & Face Shield.

The case’s dimension measures 29 mm x 40 mm x 159 mm of height, width and length

respectively. On the other hand, the face shield’s dimension measures 135 mm x 168 mm x 180

mm of height, width and length respectively. In terms of its shape & mass, the case of the product

is L-shaped rectangle with a mass of 80g and for the Face shield, it is curved arc shaped with a

mass of 60g. Also, the material used for the case is PETG, for the lens is Fresnel lens, for the

reflector is acrylic sheet, for the battery is li-po battery, while the module used are OLED display,

RTC module, Arduino Nano, TP4056 module, Ultrasonic Sensor, and Temperature sensor.

2.1. The Smart Face Shield: Arduino Based Infra-red Face shield for Protection and

Temperature Scanning was able to detect an initial temperature of 35.96 °C at 50cm distance without

ultrasonic sensor in the second row. The first trial detected a temperature of 35.44 °C, the second trial was

35.58 °C, and the third trial was 35.54 °C. It has an average temperature of 35.52 °C which is ±0.44°C

away from the initial temperature and accuracy of 1.2%. The product was able to detect an initial

temperature of 36.18 °C at 75cm distance without ultrasonic sensor in the third row. The 47 first trial

detected a temperature of 35.37 °C, the second trial was 35.43 °C, and the third trial was 35.39 °C. It has

an average temperature of 35.40 °C which is ±0.78°C away from the initial temperature and an accuracy of 2.2%. The product was able to detect an initial temperature of 36.35 °C at 100cm distance without

ultrasonic sensor in fourth row. The first trial detected a temperature of 35.17 °C, the second trial was 35.16

°C, and the third trial was 35.24 °C. It has an average temperature of 35.19 °C which is ±1.16 °C away

from the initial temperature and an accuracy of 3.2%.

2.2. The Smart Face Shield: Arduino Based Infra-red Face shield for Protection and

Temperature Scanning was able to detect initial temperature of 35.51 °C at 50cm distance with ultrasonic

sensor in the second row. The first trial detected a temperature of 35.53 °C, the second trial was 35.54 °C,

and the third trial was 35.51 °C. It has an average temperature of 35.53 °C which is ±0.02 °C away from

the initial temperature and an accuracy of 0.1%. The product was able to detect initial temperature of 35.62

°C at 75cm distance with ultrasonic sensor in the third row. The first trial detected a temperature of 35.59

°C, the second trial was 35.56 °C, and the third trial was 35.58 °C. It has an average temperature of 35.58

°C which is ±0.04 °C away from the initial temperature and an accuracy of 0.1%. The product was able to

detect initial temperature of 35.59 °C at 100cm distance with ultrasonic sensor in the fourth row. The first

trial detected a temperature of 35.54 °C, the second trial was 35.58 °C, and the third trial was 35.59 °C. It

has an average temperature of 35.57 °C which is ±0.02 °C away from the initial temperature and an accuracy

of 0.1%.

3. Three trials were conducted to know how long the Li-Po Battery would last and

discharge from its maximum voltage of 4.2 v to its nominal voltage of 3.7v. The battery lasts 3

hours 22 minutes in the first trial, 3 hours and 49 minutes in the second trial, while 3 hours and 11

minutes from its last trial. The battery of the product is discharge after it reached the minimum

safety voltage (3.2v) from its maximum voltage (4.2v). In the first trial it takes 7 hours and 45

minutes before reaching the minimum safety voltage, 9 hours and 40 minutes in the second trial,

and 7 hours and 26 minutes in trial third trial. To determine the time before the battery, reach its cut-off voltage, which is 2.8v, we made another three trials. And as seen on the table, on the first

trial, it will take 8 hours and 10 minutes before the battery reaches its cut-off voltage, while 10

hours and 2 minutes in the second trial, and 8 hours and 9 minutes in the final trial.

4. Three trials were conducted to know the duration of time needed for lithium ion-polymer

battery to charge from its cut-off voltage (2.8v) to minimum safety voltage (3.2v) through the

charging module using a UBS cable. The battery took 1 minute & 22 seconds to charge on the

first trial, 1 minute & 31 seconds to charge on the second trial, while 1 minute & 27 seconds to

charge on the third trial. To determine the duration of time the battery would charge from cut-off

voltage (2.8v) to nominal voltage (3.7v), three trials were also conducted. On the first trial, it took

29 minutes and 43 seconds to charge the battery. On the second trial, it took 30 minutes and 57

seconds to charge the battery. While on the third trial, it took 30 minutes and 28 seconds to charge

the battery. Lastly, three trials were also conducted to determine the duration of time the battery

would charge from the cut-off voltage (2.8) to maximum voltage (4.2). The battery took 1 hour

and 15 minutes to charge on the first trial, it took 1 hour and 31 minutes to charge on the second

trial, while it took 1 hour and 28 minutes to charge on the third trial.

5. In daylight setting, the virtual image data reflection is at low visibility while in nightlight

setting, the virtual image data reflection is at high visibility. In the shady light, fluorescent lamp,

and bulb light settings, the virtual image data reflection is at mid visibility.

Conclusions

After the product testing, the researchers came up with the following conclusions regarding

the effectiveness and functionality of the Smart Face Shield: Arduino Based Infra-red Face shield

for Protection and Temperature Scanning in accordance with the objectives of the study.

1. The Smart Face Shield: Arduino Based Infra-red Face shield for Protection and

Temperature Scanning had reached the accepted physical characteristics. The case has a dimension

of 29 mm x 40 mm x 159 mm of height, width and length respectively with a shape of L-shaped

rectangle. On the other hand, the face shield is a curved arc shaped that has a dimension of 135

mm x 168 mm x 180 mm of height, width and length respectively. The total weight of the case and

face shield is 145g.

2.1. The reading of temperature was quite accurate with 1.2% accuracy when the product

is 50cm away from the subject without using an ultrasonic sensor. The reading of temperature was

inaccurate with 2.2% accuracy when the distance between the product and the subject was

expanded into 75cm without using an ultrasonic sensor. The reading of temperature was inaccurate

with 3.2% accuracy when the distance between the product and the subject was expanded into

100cm without using an ultrasonic sensor

2.2. The reading of temperature when the product is 50cm, 75cm, and 100cm away from

the subject with the use of ultrasonic sensor was more accurate with 0.1% accuracy than only using

a temperature sensor.

3. The Smart Face Shield: Arduino Based Infra-red Face shield for Protection and

Temperature Scanning’s Li-Po battery would last and discharge from its maximum voltage to its

nominal voltage after at least more than 3hrs. After reaching its minimum safety voltage, the

battery would last for approximately 7hrs up to 9hrs. The battery of the product will reach its cut-

off voltage within a maximum time of 10hrs.

4. Through a charging module using a USB cable, it will take less than 2 minutes for the

Li-Po battery to charge from its cut-off voltage to its minimum safety voltage. The maximum duration of time the battery would charge from its cut-off voltage to its nominal voltage is more

than 30 minutes. In able to charge the battery of the product from its cut-off voltage to its maximum

voltage, it’ll take at least more than an hour.

5. The virtual image data reflection visibility depends on the lighting condition; it is likely

to be less visible in brighter ambient lights, and more visible in darker ambient light.

Recommendations

After drawing the conclusions of the study, the researchers hereby make the following

suggestions and recommendations:

1. Use Laser integrated display projector from known smart glasses like Focal by

North, to make the product’s design less bulky and projected data more visible,

however, it would be expensive.

2. Create a design for the Ultrasonic and temperature sensor located at the top of the

face shield to make it simpler or simply relocate the sensors without affecting its

overall functionality.

3. Add a Bluetooth module or WI-FI module to make the product easily accessible

and provide more smartphone functionality such as message notification, call

notification and etc.

4. Add a micro speaker to provide voice notification as an additional way of notifying

the user.

5. Use larger capacity battery and change the resistor value on TP4056 module to

make the product have longer battery life.

6. Add buttons or touch sensor to control the data presented at the OLED display.

7. Use the required lens which is a Plano convex lens which has a focal point of

100mm and 3x magnification to make the data more visibly clear.

8. Use thermal camera as an alternative to IR temperature sensor, however it would

more expensive.

Bibliography

Acrylic Plastic Material (n.d.). Clear Plastic Uses & Properties of Acrylic. Curbell Plastics.

https://www.curbellplastics.com/Research-Solutions/Materials/Acrylic

Alcoran-Alvarez, G., Alvarez, D., Garcia, M. (2020). Automated Social Distancing Gate with

Non-Contact Body Temperature Monitoring Using Arduino Uno. International Research

Journal | of | Engineering | and | Technology | (IRJET), | 7(7), | 4352 | –

4357.https://www.researchgate.net/publication/349195020_Automated_Social_Distancin

g_Gate_with_Non-Contact_Body_Temperature_Monitoring_Using_Arduino_Uno. (https://www.researchgate.net/publication/349195020_Automated_Social_Distancing_Gate_with)

Costanzo, S. (2020). A Non-Contact Integrated Body-Ambient Temperature Sensors Platform to

Contrast | COVID-19. | MDPI. | Retrieved | November | 21, | 2021, | from

https://www.mdpi.com/2079-9292/9/10/1658

De Vaus, D. A. Research Design in Social Research. London: SAGE, 2001; Trochim, William

M.K. Knowledge Base - Research Methods Knowledge Base (conjointly.com) (https://conjointly.com/kb/) 2006.

How to Get Great Results with an Infrared Thermometer. (2021, May 9). Fluke. Retrieved

February 3, 2022, from https://www.fluke.com/en-ph/learn/blog/temperature/how-to-

get-great-results-with-an-infrared-thermometer

imageHOLDERS. | (2021, | February | 4). | Covid-19 | Temperature | Screening | Kiosks.

https://www.imageholders.com/covid-19-temperature-screening-kiosks/

Infrared thermometer on the wall (iThermowall): An open source and 3-D print infrared

thermometer for fever screening. (2021, April 1). ScienceDirect. Retrieved November 21,

2021, from https://www.sciencedirect.com/science/article/pii/S2468067220300778

Petrovic, Nenad & Kocić, Đorđe. (2020). IoT-based System for COVID-19 Indoor Safety

Monitoring. https://www.researchgate.net/publication/343231422_IoT-

based_System_for_COVID-19_Indoor_Safety_Monitoring (https://www.researchgate.net/publication/343231422_IoT-based_System_for_COVID-19_Indoor_Safety_Monitoring)

Mauer, A. (2016, September 24). Arduino Glasses a HMD for Multimeter. Hackaday.Io.

https://hackaday.io/project/12211/instructions.

P., N. N., V. (2021, May 28). Contactless Mobile Thermometer | International Journal of Modern

Agriculture. Modern-Journals. Retrieved November 21, 2021, from http://www.modern-

journals.com/index.php/ijma/article/view/1261

Rayan, R. (2021, November 24). How Long to Charge 1S-4S(3.7V-14.8V) RC LiPo Batteries.

Majestic RC. Retrieved February 3, 2022, from https://majesticrc.com/how-long-does-it-

take-to-charge-a-different-v-lipo-battery/ (https://majesticrc.com/how-long-does-it-take-to-charge-a-different-v-lipo-battery/)

Bell, | S. | (2009, | January | 1). | Experimental | Design. | ScienceDirect.

https://www.sciencedirect.com/science/article/pii/B9780080449104004314

Twi. (n.d.). What is PETG? (Everything You Need To Know). Retrieved February 3, 2022, from

https://www.twi-global.com/technical-knowledge/faqs/what-is-petg

Ultrasonic Sensors Knowledge Part 4. (2018, July 20). Pepperl+Fuchs. Retrieved February 3,

2022, from https://www.pepperl-fuchs.com/global/en/25518.htm

# Appendices

Appendix A

Picture of the Product

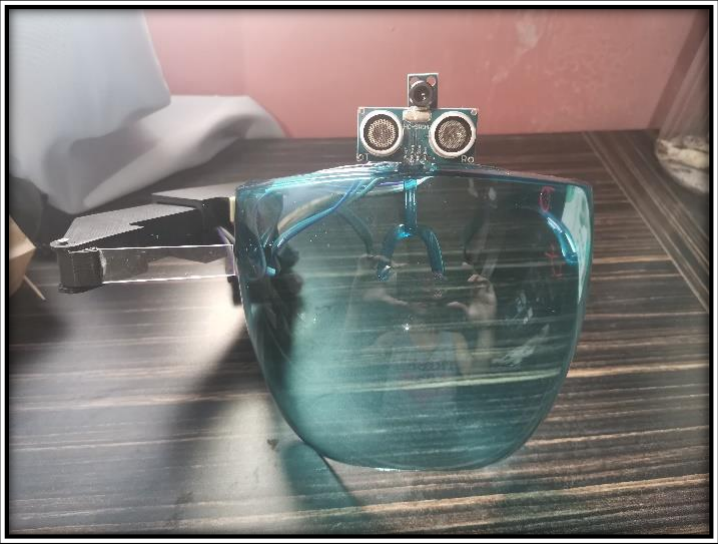
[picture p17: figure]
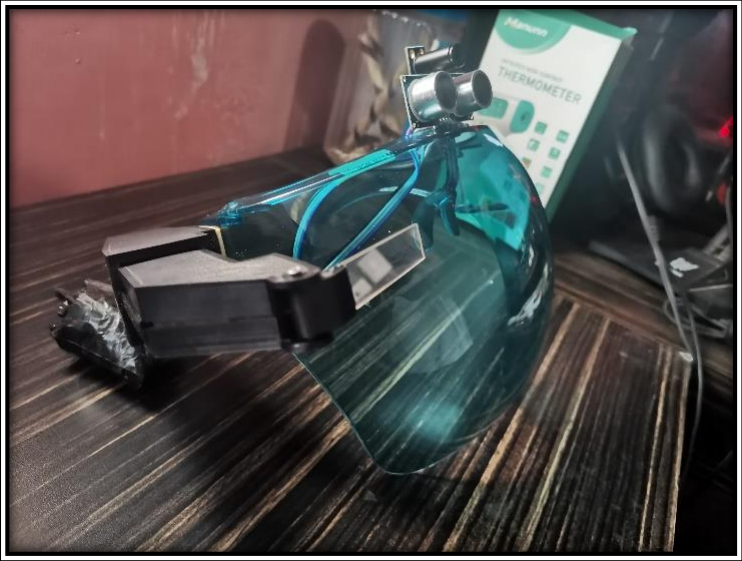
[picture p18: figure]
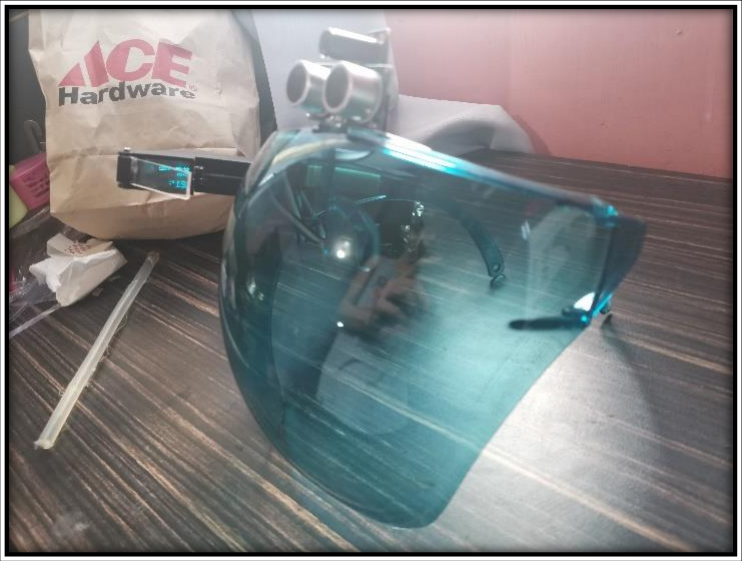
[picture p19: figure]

Appendix B

Financial Statement

MATERIALS | AMOUNT
Arduino Nano | Php 238
MLX90614 Temperature Sensor | Php 1357.48
HC-SR04 Ultrasonic Sensor | Php 59
DS3231 Real-time Clock Module | Php 148
Organic Light-Emitting Diode Display | Php 170
Fresnel Lens | Php 146
Micro DC Vibration Motor | Php 49
Lithium-Polymer Battery | Php 534
Polyethylene Terephthalate Glycol Case | Php 400
TOTAL | Php 3,101

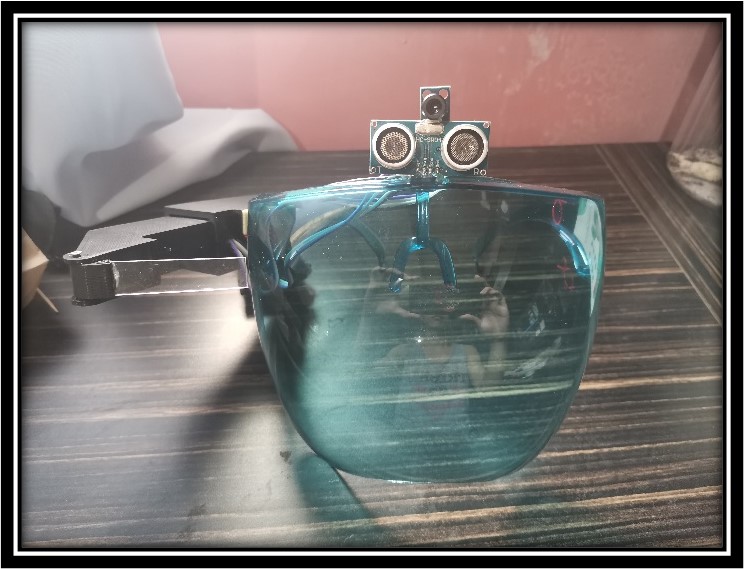
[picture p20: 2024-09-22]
assets/asf-photo1.jpg

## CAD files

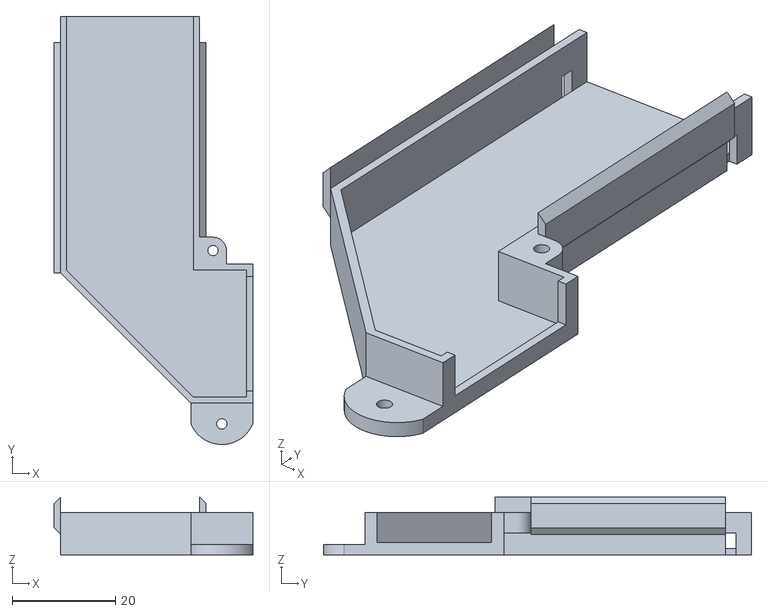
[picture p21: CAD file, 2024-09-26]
case-3d-model/BOT-ARM.stl
38.5 x 83.0 x 11.2

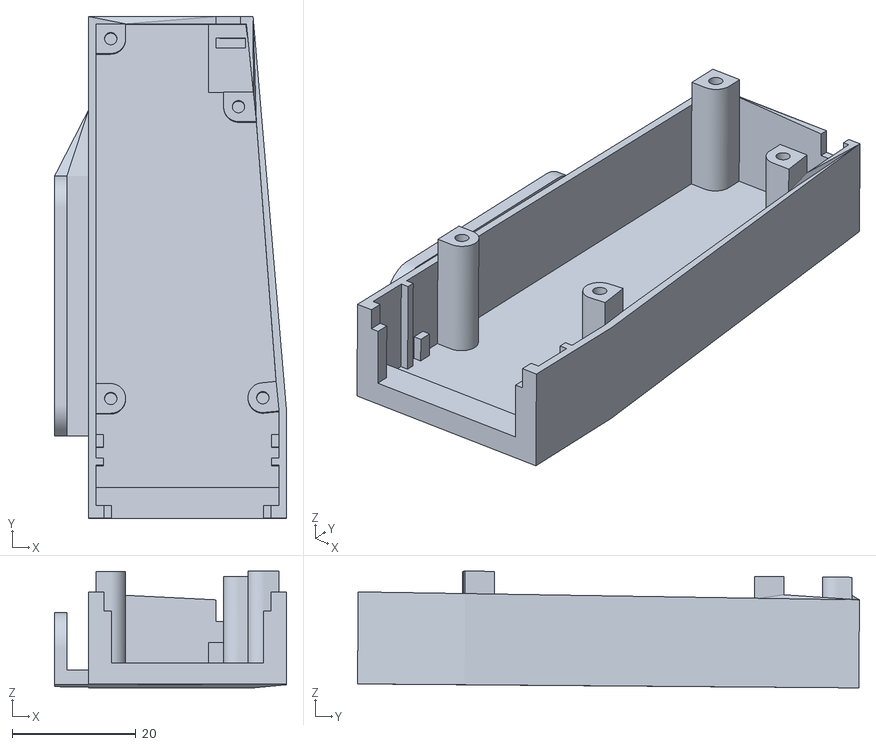
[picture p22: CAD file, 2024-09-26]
case-3d-model/TOP-BODY.stl
37.5 x 81.1 x 18.9

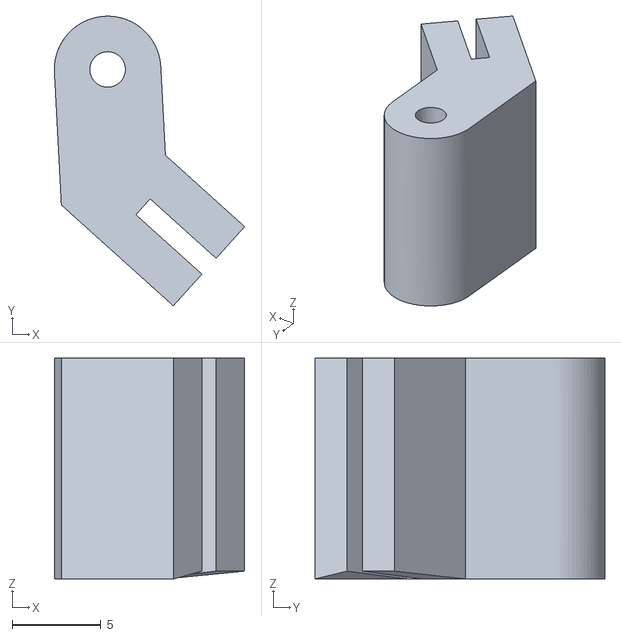
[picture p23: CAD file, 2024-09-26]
case-3d-model/REFLECTOR-BODY.stl
10.7 x 16.3 x 12.4

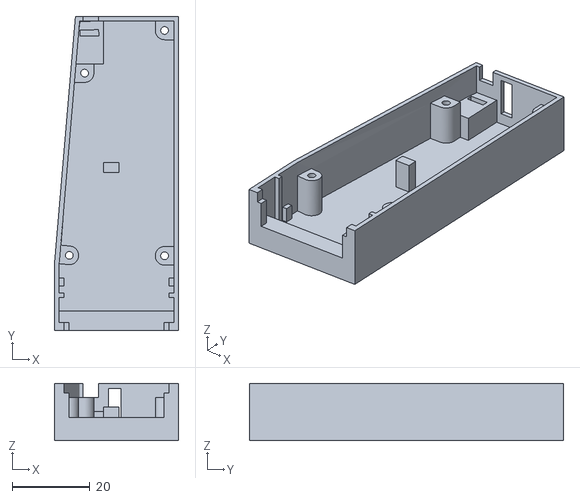
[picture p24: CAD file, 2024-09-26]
case-3d-model/BOT-BODY.stl
32.0 x 81.0 x 14.8

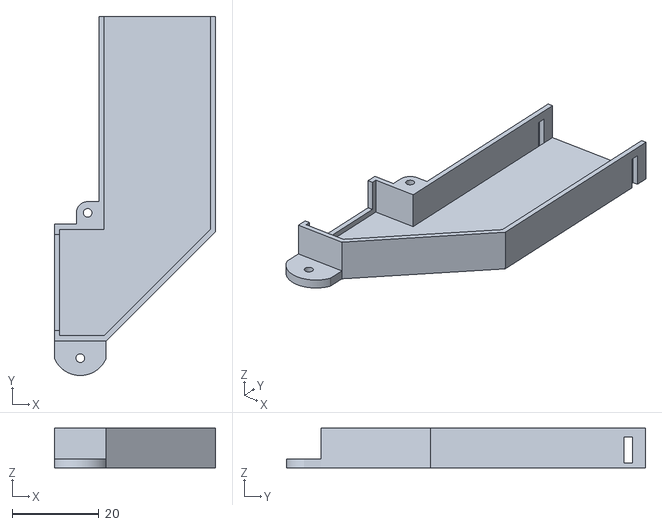
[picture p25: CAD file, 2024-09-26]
case-3d-model/TOP-ARM.stl
37.3 x 83.0 x 9.24

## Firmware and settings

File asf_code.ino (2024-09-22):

#include <NewPing.h>
#include <Adafruit_MLX90614.h>
#include <SPI.h>
#include <Wire.h>
#include <Adafruit_GFX.h>
#include <Adafruit_SSD1306.h>
#include "RTClib.h"

// Global variables and definitions
char *typeName[] = {"Object:", "Ambient:"};
Adafruit_MLX90614 mlx = Adafruit_MLX90614();
RTC_DS3231 rtc;
char daysOfTheWeek[7][12] = {"Sunday", "Monday", "Tuesday", "Wednesday", "Thursday", "Friday", "Saturday"};

#define SCREEN_WIDTH 128      // OLED display width, in pixels
#define SCREEN_HEIGHT 64      // OLED display height, in pixels
#define OLED_RESET 4          // Reset pin for the OLED display
#define VIBRATION_MOTOR 10    // Pin for the vibration motor
#define TRIGGER_PIN 11        // Ultrasonic sensor trigger pin
#define ECHO_PIN 12           // Ultrasonic sensor echo pin
#define MAX_DISTANCE 100      // Maximum distance for the ultrasonic sensor in cm
#define VCC2 2                // Additional VCC (5V) for the ultrasonic sensor

NewPing sonar(TRIGGER_PIN, ECHO_PIN, MAX_DISTANCE); 
Adafruit_SSD1306 display(SCREEN_WIDTH, SCREEN_HEIGHT, &Wire, OLED_RESET);

void setup() {
  // Setup pins and initialize components
  pinMode(VCC2, OUTPUT);                // Extra VCC for ultrasonic sensor
  digitalWrite(VCC2, HIGH);             // Set extra VCC to HIGH (5V)
  pinMode(VIBRATION_MOTOR, OUTPUT);     // Pin for vibration motor
  Serial.begin(9600);                   // Start serial communication
  delay(3000);                          // Wait for console opening
  
  // Initialize RTC
  if (!rtc.begin()) {
    Serial.println("Couldn't find RTC");
    while (1);
  }
  if (rtc.lostPower()) {
    Serial.println("RTC lost power, setting time.");
    rtc.adjust(DateTime(F(__DATE__), F(__TIME__))); // Set RTC to compile time
  }
  
  // Initialize OLED display
  display.begin(SSD1306_SWITCHCAPVCC, 0x3C);  // Initialize with I2C address 0x3C
  display.clearDisplay();
  display.display();                           // Display buffer content
  display.setTextColor(WHITE, BLACK);
  display.drawRect(95, 30, 3, 3, WHITE);      // Degree symbol ( ° )
  draw_text(60, 57, "cm", 1);
  draw_text(100, 30, "C", 1);
  
  // Check temperature and control vibration motor
  if (mlx.readObjectTempC() >= 37.5) {
    digitalWrite(VIBRATION_MOTOR, HIGH);
  } else {
    digitalWrite(VIBRATION_MOTOR, LOW);
  }
}

void loop() {
  DateTime now = rtc.now();
  int distanceCM = sonar.ping_cm();           // Get distance in cm
  
  // Display date
  display.setTextSize(1);
  display.setCursor(0, 0);
  display.print(daysOfTheWeek[now.dayOfTheWeek()]);
  
  char currentDate[16];
  sprintf(currentDate, "%02d/%02d/", now.day(), now.month()); // Leading zeros for day and month
  display.setCursor(62, 0);
  display.print(currentDate);
  
  display.setCursor(102, 0);
  display.print(now.year(), DEC);
  
  // Display time
  char buffer[16];
  sprintf(buffer, "%02d:%02d:%02d", now.hour(), now.minute(), now.second());
  display.setCursor(40, 13);
  display.setTextSize(1);
  display.print(buffer);
  
  // Display temperature
  display.setTextSize(2);
  display.setCursor(33, 30);
  display.print(mlx.readObjectTempC());
  display.display();
  
  // Display distance
  display.setTextSize(1);
  display.setCursor(45, 57);
  display.print(distanceCM);
  display.display();

  // Output to Serial
  Serial.println(distanceCM);
  Serial.println(mlx.readObjectTempC());
  
  delay(500);  // Delay for half a second
}

// Function to display text on the OLED
void draw_text(byte x_pos, byte y_pos, char *text, byte text_size) {
  display.setCursor(x_pos, y_pos);
  display.setTextSize(text_size);
  display.print(text);
  display.display();
}
